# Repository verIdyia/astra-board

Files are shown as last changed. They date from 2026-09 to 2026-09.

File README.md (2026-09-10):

# Astra Board

ESP32-C3 development board built as a documented AI-assisted PCB experiment.

## Status

**Manufacturing paused due to cost (2026-09-10).** The owner reported approximately **US$123 for Standard PCBA** and **US$85 for Economic PCBA** in the 10-board quote discussion, and chose to stop procurement. These are owner-reported figures, not an independently verified complete checkout total; shipping/tax inclusion and complete LED assembly are unconfirmed. No order or payment was submitted.

KiCad ERC and DRC passed with zero reported violations on 2026-09-10. The repository QR is added and independently decoded from the KiCad export. Manufacturing files are in `fab/rev2/`; supplier assembly-preview verification is pending. JLCPCB currently rejects the LED for Economic PCBA; alternative-part eligibility is inconsistent and remains unresolved. The support inquiry is drafted but unsent. Revision 2 includes the electrical-review routing and power-copper repair. USB signal integrity and regulator temperature remain unverified. No hardware has been manufactured or tested.

## Hardware

- 60 × 40 mm, two layers, front-side SMT
- ESP32-C3-WROOM-02, native USB-C, 3.3 V regulator
- Eight addressable RGB LEDs, two user buttons, BOOT and RESET
- Passive buzzer, OLED header, Qwiic connector and GPIO expansion
- 16 SMT BOM lines / 50 assembled components; buzzer and two headers are owner-soldered

Open `hw/astra-board.kicad_pro` with KiCad 10. Local footprint variants are in `lib/Astra.pretty`; the project footprint table resolves them relative to the project.

See `BRIEF.md` for requirements, `parts/DECISIONS.md` for design choices and known limitations, and `log/` for the experiment record. `parts/bom-candidates.csv` records selected parts and sourcing evidence. Firmware and a machine-readable pinout are planned but not yet implemented.

Raw recordings, account responses, intermediate router output and draft manufacturing files are deliberately excluded. This repository is not yet a fabrication release.

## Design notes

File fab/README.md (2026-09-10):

# Fabrication status
`rev1/` is the current package for supplier review. It includes the repository QR, Gerbers, drills, BOM/CPL and machine-check reports. No order has been placed.
DRC and ERC report zero violations. BOM has 16 SMT lines / 50 components, and CPL has 50 top-side rows matching the schematic. BZ1, J3 and J4 are owner-soldered.
All exports use the absolute origin; CPL Y follows KiCad's Y-up convention. Rotations are raw KiCad angles and still require JLCPCB assembly-preview verification. Hardware and thermal performance are unverified.
The STEP preview remains local and omits the absent USB-C 3D model. Draft and intermediate artifacts are excluded from version control.

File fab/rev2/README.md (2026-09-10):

# Revision 2 manufacturing package — PCB silk REV 1.1

**Procurement paused by the owner due to cost on 2026-09-10.** Preserved for future supplier review; no order/payment submitted. Economic LED eligibility remains unresolved and supplier assembly preview is incomplete. ERC and DRC: zero violations. BOM: 16 lines, 50 SMT components; CPL: 50 front-side placements. Seven extended lines are justified in parts/DECISIONS.md. BZ1/J3/J4 are owner-soldered and excluded.

Gerber ZIP and CPL use the common absolute KiCad coordinate origin; negative CPL Y is intentional. JLCPCB placement rotations/polarity must be reviewed before ordering. STEP visualization in hw/export omits J1 because its installed model is missing.

USB routing was shortened and power routing/thermal copper increased. Controlled differential impedance, USB signal integrity, regulator temperature at load and physical QR scanning remain unverified. See reviews/2026-09-10-pcb-review.md and log/03-layout.md.

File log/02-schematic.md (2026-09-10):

# 02 — Schematic — 2026-09-10 15:26–15:28 KST

## Phase
Schematic completed; moving to layout.

## What happened
Built three hierarchical pages with KiCad MCP batch placement, sourcing properties and global net labels. Native USB maps to GPIO18/19; I2C GPIO4/5; pixels GPIO6; buzzer GPIO7; user buttons GPIO0/1; BOOT GPIO9. GPIO2/8 receive external pull-ups. Expansion carries six remaining GPIOs, 3V3, 5V and two grounds. Last LED output and USB SBU pins are deliberately unconnected.

## Human interventions
No schematic intervention. Repo URL question remains pending for layout QR.

## Verification
- ERC errors: 0; warnings: 0 on the first run.
- DRC: not run yet.
- kicad-cli sch erc --format json generated hw/export/erc-attempt1.json.
- kicad-cli XML netlist export verified 53 physical components: 50 SMT, 3 owner-soldered THT. Every component has LCSC and JLC_BASIC; USB and I2C endpoint checks passed.
- Default KiCad ignored checks are recorded in the JSON; no check was disabled by the agent. In particular footprint-filter checking is a default ignored item, so library existence is checked separately.
- SVG exports of all three pages are in hw/export/schematic/.
- Unverified: rendered-page visual QA, analog stability/thermal behavior, hardware operation. ERC does not prove those.
- MCP created a PCB with 53 footprints and assigned 188 pads; NC/NPTH pads were intentionally unmatched.

## Scoreboard
ERC 0 / DRC not run / weekly usage 65%→66% / 5h absent / human time not measured.

## Media candidates
Raw: media/raw/run01-20260910-151816.mov.
- 00:05:20 — parts gate, before schematic work
- 00:09:22 — first ERC, zero violations

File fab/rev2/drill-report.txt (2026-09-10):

Drill report for astra-board.kicad_pcb
Created on 2026-09-10T19:54:18

Copper Layer Stackup:
    =============================================================
    L1 :  F.Cu                      front
    L2 :  B.Cu                      back

Drill file 'astra-board-PTH.drl' contains
    plated through holes:
    =============================================================
    T1  0.300mm  0.0118"  (57 holes))
    T2  0.300mm  0.0118"  (12 holes))
    T3  0.600mm  0.0236"  (4 holes)  (with 4 slots)
    T4  1.000mm  0.0394"  (16 holes))

    Total plated holes count 89

Drill file 'astra-board-NPTH.drl' contains
    unplated through holes:
    =============================================================
    T1  0.650mm  0.0256"  (2 holes))

    Total unplated holes count 2

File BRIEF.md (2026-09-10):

# astra-board — project brief

Read this before doing anything. `AGENTS.md` next to this file has the working rules.

## Why this project exists

The owner is a PCB / embedded firmware engineer (6 years, memory burn-in boards, I2C/SPI device firmware). This month there are many posts claiming GPT-6 Astra can one-shot a PCB. This project tests that claim end to end, honestly, and documents it publicly on X.

The rule of the experiment: **the human does not open the schematic or PCB editor.** The human writes prompts, reviews outputs, approves the JLCPCB payment, and solders the through-hole parts. Everything else is done by Astra through the KiCad MCP server, `kicad-cli`, and (only where unavoidable) Computer Use.

Wins and failures are both published. Do not hide errors, do not paper over an ERC/DRC violation, do not claim something is verified when it is not.

## What we are building

A small dev board that is easy for an AI agent to write firmware for. It will be given away to a few people on X; they should be able to plug it in, point Codex/Claude at this repo, and say "make it do something."

Board concept:

- MCU: ESP32-C3 module (native USB serial/JTAG, WiFi, Arduino / ESP-IDF / MicroPython support, very well represented in training data). If you believe a different part is clearly better for this purpose, say so in `parts/DECISIONS.md` with reasons, but the default is C3.
- Power: USB-C receptacle (16-pin, 5.1 kΩ CC pull-downs), 5 V → 3.3 V LDO rated ≥ 600 mA (WiFi TX peaks), proper decoupling.
- Things that give immediate visible / audible feedback:
  - 8 × addressable RGB LEDs (WS2812B family or compatible), in a row or arc
  - 2 × user tactile buttons, plus BOOT and RESET buttons
  - 1 × passive buzzer with a transistor driver
  - 0.96" I2C OLED (SSD1306, 4-pin module) on a through-hole header — the human solders this
- Expansion: 1 × Qwiic / STEMMA QT connector (JST SH 1.0 mm, 4-pin) on the same I2C bus, and a through-hole header breaking out the remaining GPIOs, 3V3, 5V, GND.
- Silkscreen: board name, pin labels on every header, a QR code pointing at this repo.
- Repo will contain `board.json` (machine-readable pinout) and firmware examples. Example firmware #1: a "quota gauge" that reads a JSON endpoint and shows remaining Astra / Claude usage on the LEDs and OLED.

## Hard constraints

- 2-layer, single-side SMT, JLCPCB Economic PCBA. Board size target ≤ 60 × 40 mm.
- JLCPCB **basic** parts first. Every **extended** part costs a feeder fee; each one must be justified in `parts/DECISIONS.md`. Aim for ≤ 4 extended parts (module, USB-C, Qwiic, LEDs are the likely ones).
- Passives 0603 or larger (hand rework must be possible). No BGA, no QFN with exposed pad unless it is inside the module.
- Through-hole parts (headers, OLED header, buzzer if THT) are **not** assembled by JLCPCB; the human solders them. Keep them few.
- SMT part count ≤ 20 lines in the BOM.
- Design rules: ≥ 0.2 mm trace / 0.2 mm clearance, ≥ 0.2 mm drill, ≥ 0.6 mm via pad (JLCPCB standard capabilities).
- Only use symbols and footprints that actually exist in the KiCad 10 standard libraries or in `lib/` inside this project. Never invent a footprint. If a part needs a footprint that does not exist, say so and stop.
- Every LCSC part number must be verified against the JLCPCB parts database (the MCP server ships `download_jlcpcb.py`) or jlcpcb.com. Never guess an LCSC number. Mark anything you could not verify as UNVERIFIED.

## Phases and gates

Run the phases **back to back in one session** — this is the point of the experiment: can it go start to finish in one day? Each phase has a machine-checkable gate. Pass the gate, write the phase log, move on. Do not wait for the human between phases.

There are exactly **two hard stops** where you wait for the human:

- **Before payment on JLCPCB.** Show the cart total, the assembly preview (part rotations, polarity), and the extended-part count. The human clicks pay. Never submit payment yourself.
- **A gate that fails after two honest attempts.** Stop, write down what is failing and what you tried, and ask. Do not loop.

1. **Parts** → `parts/bom-candidates.csv` (columns: `role, qty, mpn, manufacturer, lcsc, basic_or_extended, unit_price_usd_at_10, stock, kicad_symbol, kicad_footprint, datasheet_url, note`) + `parts/DECISIONS.md` (MCU module choice — compare at least ESP32-C3-MINI-1 vs ESP32-C3-WROOM-02 — LDO, LED package, USB-C receptacle, buzzer + driver, Qwiic connector, button footprint, every extended part and why it earns its feeder fee, estimated PCBA cost for 10 boards). Prefer stock > 1,000. Gate: every LCSC number verified; every symbol/footprint name confirmed to exist.
2. **Schematic** → `hw/astra-board.kicad_sch`. Gate: `kicad-cli sch erc --format json` reports 0 errors; warnings listed with a reason each.
3. **Layout** → `hw/astra-board.kicad_pcb`. Gate: `kicad-cli pcb drc --format json --exit-code-violations` exits 0. Export SVG (both sides) and STEP to `hw/export/` for the human to look at later.
4. **Fab files** → `fab/` (gerbers, drill, POS, BOM/CPL in JLCPCB column format). Gate: files present, BOM lines match the schematic, CPL row count matches SMT part count.
5. **Order** → JLCPCB via browser up to the payment page. **Hard stop.**
6. **Firmware** → `fw/` examples + `board.json` + `fw/AGENTS.md` for the people who receive the board. Gate: the example firmware builds for the chosen module. Hardware test happens when the boards arrive.

Write a log entry per phase (`log/01-parts.md`, `log/02-schematic.md`, … using `log/TEMPLATE.md`). The human will read them afterwards, not during.

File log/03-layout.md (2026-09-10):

# 03 — Layout — 2026-09-10 15:28–15:42 KST

## Phase
Layout gate failed twice. Stopped; no fabrication package or order created.

## What happened
Placed 53 footprints on a 60 × 40 mm, two-layer board with SMT on the front. Corrected mechanical placement conflicts with file-based geometry checks. Routed using local Freerouting 2.4.1, then checked the saved result with KiCad CLI. Added rear ground fill and a front 3V3 thermal copper region. Header labels are on the back; buttons, board name and LED indices are on the front. Public-repo QR remains pending the URL.

The standard module footprint had 0.2 mm thermal drills. A documented derivative in lib/Astra.pretty increases the twelve holes to 0.3 mm without changing pad locations/sizes. This fixed the drill constraint; no drill violations remain. No KiCad editor was used.

## Attempts and what failed
1. `kicad-cli pcb drc --format json --exit-code-violations --refill-zones -o hw/export/drc-attempt1.json hw/astra-board.kicad_pcb`: exit 5; 70 errors, 65 warnings, 0 unconnected. Errors: 66 undersized 0.15 mm trace segments, two courtyard overlaps and two copper-edge clearances. Warnings: 30 undersized text, 20 silk overlap, nine silk over copper, six silk-edge clipping.
2. Moved C2/R8/J2 to resolve mechanical/edge issues. Moved problematic body outlines and LED pin-number text to fabrication layer, enlarged actual silk text to 0.8 mm, and repositioned labels. Removed prior routing and rerouted with `--router.automatic_neckdown=false --router.neck_width_um=0`; exported DSN smd_smd clearance also raised from the exporter's 0.05 mm to 0.2 mm. CLI DRC with the same flags, output drc-attempt2.json: exit 5; 32 errors and 14 warnings in violations, plus two unconnected-item errors. Total 34 errors / 14 warnings. Thirty-one trace segments remain 0.15 mm despite the requested router override. One thermal connection at U2 pad 2 has only one required spoke; two disconnected items are islands within the 3V3 zone. All prior placement, edge and silk-size/overlap errors are gone.

The second SES still contained width values 1500 and 2000 in its coordinate scale. Those were printed before import; I should have investigated the remaining 1500 widths instead of assuming the flag had worked. The actual router behavior is not yet explained (fanout or settings precedence are possibilities, not verified causes).

The 14 library-footprint mismatch warnings are D1–D8, SW1–SW4, U1 and J1, whose silk graphics were relocated to F.Fab. They need matching local library variants or another consistent artwork solution. They have not been suppressed.

A requested Power net class was saved in the project, but the MCP warned its in-memory assignment failed; DSN still places all nets in kicad_default. Therefore the intended 0.4 mm power routing was NOT achieved. Do not claim otherwise.

SES import updated disk without refreshing the MCP file-change fingerprint. Subsequent autosaves were refused. Reloaded from disk and reapplied zones/labels; did not force-overwrite the routed file. No server code was modified.

## Human interventions
No layout-editor intervention. Asking for authorization to continue after the two-failure hard stop. Repo URL question remains unanswered.

## Verification
- ERC: final recheck after local footprint reference change, 0 errors / 0 warnings (erc-final.json).
- DRC final: 34 errors including two unconnected-item reports; 14 warnings; exit 5.
- Minimum drill change verified by DRC (no drill violations); minimum trace requirement still fails.
- Front and mirrored back SVGs and STEP successfully exported as review-NOT-FOR-FAB files.
- File-based rendered front silk/mask inspected; no screenshot used as design-rule verification.
- Unverified: QR, impedance/USB pair lengths, thermal/current performance, detailed datasheet mechanical match, successful final DRC, fab consistency, JLC assembly preview, firmware build and hardware.

## Scoreboard
ERC 0 / DRC 34 errors + 14 warnings / weekly usage 66%→68% (resumed session 65%→68%) / 5h absent / human time not measured.

## Media candidates
Raw: media/raw/run01-20260910-151816.mov.
- 00:09:22 — first schematic ERC passed
- 00:17:43 — first routed PCB DRC failed
- 00:21:44 — second DRC and hard stop

## Resumed session — 2026-09-10 15:45–15:54 KST
User authorized continued fixes and computer use. No editor was running. Recording run02 started with a persistent display-awake assertion; weekly usage 68%→70%.

New gate attempt 1 (overall attempt3): 31 track-width errors, two unconnected errors, zero warnings. The earlier claim that MCP widened the tracks was incorrect: the advertised modify_trace parameter traceUuid is rejected by the backend as “Missing trace identifier”; its nested success:false was initially missed. The tool did not change those widths. No server code was changed. The local library mismatches were fixed by generating four artwork variants directly from existing standard library parts, then synchronizing 14 schematic and board references. Two failed SWIG copy attempts were abandoned in favor of loading the known original library footprints. The minimum-hole rule was updated to 0.2 mm; actual existing 0.3 mm drills remain unchanged.

New gate attempt 2 (overall attempt4): seven unconnected errors and three dangling-track warnings, exit 5. Width and clearance errors are now zero; library mismatch warnings are zero. KiCad-bundled Python widened all 31 affected tracks and reread the saved board to verify the minimum width is 0.2 mm. A prospective shape-clearance check found one conflict with a 3V3 via; a 0.035 mm shift of the connected 45-degree/vertical GND segments removed that conflict. No cross-net GND pad/track/via collisions remained in the preflight check, and DRC confirmed no clearance failures.

The remaining seven connectivity errors and three dangling warnings are all on +3V3, around U2 and C4/C5/C6. The earlier large 3V3 pour had two disconnected sections even with solid connections/island removal. It was removed for replacement with a smaller solid thermal region, but the advertised MCP add_zone command returned “Unknown command”. I ran DRC before resolving that command failure, so the replacement zone is absent. The affected traces had previously depended on that pour for connectivity. Next correction must establish explicit 3V3 copper continuity and sufficient LDO thermal copper, verify that it is saved, then run the gate; do not merely suppress these reports.

All four local footprint variants are based on existing standard parts; no pad geometry changed beyond the already documented twelve module drill enlargements. Refreshed BOM footprint references accordingly. Thermal behavior, USB signal integrity, repo QR and manufacturing remain unverified. No fab/order/firmware phase was started.

Human interventions: user permitted this resumed correction round; another two-attempt stop reached. Further fixes await permission. Public repo URL is still missing.

Media candidates: media/raw/run02-20260910-154511.mov.
- 00:03:27 — resumed DRC exposes failed width command
- 00:07:17 — saved widths verified; remaining 3V3 connectivity failure

## Third repair session — 2026-09-10 15:57–16:02 KST
Human intervention: user said “응” to resume the failed layout repair.
Restored the 3V3 zone, directly connected pads, and added one clearance-checked 0.4 mm back-layer bridge with 0.6/0.3 mm vias. Filled copper was saved using a retained pcbnew ZONE_FILLER instance.
Verification: drc-attempt5: 2 unconnected errors, 0 other violations; drc-attempt6: 1 unconnected error, 0 other violations (warnings included). Layout gate still fails; not ready for fabrication. Two straight-bridge candidate searches for the remaining island collided with existing copper. Those failed candidates were not written. Stop retained per AGENTS/BRIEF; remaining connection needs a changed route.
Quota: weekly 70% at start and end; five-hour window unavailable.
Media candidates: run03 00:00:00 repair start; 00:04:12 remaining island and stop. Existing review exports predate this repair and are not fabrication artifacts.

## Fourth repair session — 2026-09-10 16:03 KST
Human intervention: user said “응” to authorize rerouting the last island.
Moved a short EN segment to B.Cu. The initial 1.0 mm via separation left the 3V3 passage closed (attempt7: one unconnected). Increased spacing to 1.4 mm; attempt8 exits 0, zero errors/warnings/unconnected. No rules relaxed. Saved zone fill retained.
ERC rerun: zero violations in erc-final.json. Front/back SVGs and STEP refreshed. Exported SVGs were rendered and inspected for copper continuity, antenna clearance and header label readability. STEP omits J1 because its installed 3D model is absent; mechanical assembly and hardware behavior remain unverified.
The DRC gate passes, but the required repository QR is still pending the actual public URL. Asked user for URL; no placeholder inserted.
Quota at start 70%, DRC pass 71%; five-hour window unavailable.
Media candidates: run04-20260910-160313.mov, 00:00:48 EN crossing change; 00:01:23 DRC passes. Latest exports remain named NOT-FOR-FAB while QR is pending.

## Repository QR completion — 2026-09-10 16:15 KST
Public repository created after user authentication. Added its QR on B.Silkscreen, 11.1 mm square with 0.3 mm cells and quiet border. DRC after the QR: zero violations and zero unconnected. Independent ZXing decode of the actual KiCad SVG raster matched https://github.com/verIdyia/astra-board. Physical scan quality awaits fabricated hardware. Front/back SVG and STEP refreshed; STEP still omits the absent J1 model.
Media: run05 00:01:02 QR insertion; 00:02:10 fabrication validation.

## Electrical review repair — 2026-09-10 19:11–19:30 KST — paused
Human intervention: user authorized fixing the review findings and proceeding directly. No PCB editor was open at the pre-edit check. Work stayed in hw/rework; published PCB and fabrication files were not overwritten.
Moved USB-C, module and USB resistors; shortened the MCU-side P/N traces to approximately 2.325/2.408 mm with no vias. Assigned power nets to the 0.6 mm class, corrected router-generated undersized tracks to at least 0.2 mm, moved the existing module bulk capacitor closer, and increased regulator-tab front copper to approximately 497 mm². This is candidate geometry, not electrical qualification.
First complete gate: kicad-cli pcb drc --format json --exit-code-violations, report hw/rework/drc1.json, failed: one courtyard overlap, seven dangling-via warnings, three unconnected reports. A saved follow-up candidate (rev2-fixed.kicad_pcb) addresses those items; it was not subjected to a second full DRC because USB routing remained unsatisfactory. Native courtyard checks reported zero overlaps for that candidate.
Two local USB-ESD route attempts then failed. First, rotated U4's power/ground connections obstructed signal escape; second, removing the two obstructing segments allowed both ESD pin ties, but the N connection to the connector still could not be routed by the local clearance-aware search. No complete rotated-USB board was saved. Stopped per AGENTS.md: do not loop on the same failing fix more than twice. Proposed next step is a new ESD placement and pair-first routing with surrounding copper rerouted afterwards.
Verification: revised DRC is NOT passed; schematic unchanged and ERC not rerun in this repair (previous published ERC zero). Thermal behavior, USB impedance/length matching, assembled-board operation and JLC placement preview remain unverified. No revised fab exports, uploads, order or payment occurred. Existing fab/rev1 is superseded in intent by the pending electrical repair and should not be ordered.
Quota: weekly 74% to 77%; five-hour window unavailable. Recording stopped normally.
Media candidates: media/raw/run07-20260910-191138.mov.
- 00:08:19 — first complete revised-layout DRC
- 00:18:40 — two local USB route failures and preserved-candidate stop

## Resumed USB repair — 2026-09-10 19:31 KST — two-gate stop
User authorized continuation. Recording run08 started; the PCB editor was not running. Reversed the local search direction to escape from the connector's narrow USB pads at their exact coordinates. This avoided the coarse 0.2 mm search-grid alignment issue and produced a complete saved USB candidate. Routing all narrow-pad connections this way succeeded; previous unsuccessful searches were not evidence that the physical routing was impossible.
First resumed gate, hw/rework/drc-usb1.json: four errors (two NPTH-to-copper clearances, one BUZZ_BASE-to-Q1 clearance, one starved J1 ground thermal), plus one unconnected item; zero warnings. Reduced two short 5V neckdown segments from 0.45 to 0.35 mm to clear the connector locating hole, rerouted the BUZZ_BASE segment, made the connector ground pads solid-connected to the ground pour, and connected the isolated ground region.
Second resumed gate, hw/rework/drc-usb2.json: ZERO errors, ZERO unconnected items, ONE warning, exit 5. Two same-net ground vias at (149.5,109.9375) and (149.5,110.1375) have overlapping 0.3 mm drills. The local search ignored same-net copper obstacles and consequently did not enforce physical drill separation between these vias. No warning was excluded. Stop per BRIEF after two failed gates. Next fix: reuse the existing ground via instead of the new adjacent via, preserving the copper connection, then refill and rerun DRC.
Last candidate: hw/rework/gate2.kicad_pcb. Original PCB and fab/rev1 remain untouched. ERC not rerun because the schematic did not change. USB signal integrity/impedance and thermal operation are unverified; DRC alone cannot verify them. No fabrication update, browser upload, order or payment.
Media candidates: run08-20260910-193144.mov, connector-escape repaired/first DRC and final single-warning stop; exact timestamps are in the adjacent markers TSV. Usage at session start: weekly 77%; five-hour absent. End usage recorded in log/usage.tsv.

## Via repair and layout gate passed — 2026-09-10 19:52–19:54 KST
User authorized continuing. Removed the redundant GND via; its attached copper endpoints are inside the retained 0.6 mm via annulus, so no separate drill is required. Refilling saved copper and running kicad-cli pcb drc --format json --exit-code-violations produced zero violations and zero unconnected items, exit 0. No rule or severity changed.
Promoted the verified candidate to hw/astra-board.kicad_pcb and its power net assignments to the main project; updated silk REV 1.0 to REV 1.1. Reran DRC on the main board with its actual library table: zero violations/unconnected, exit 0. Schematic ERC rerun: zero violations. Reports are in fab/rev2.
Front/back SVGs were exported and inspected. The actual back SVG raster still decodes the exact repository URL with ZXing. STEP exported, but the installed USB-C model remains missing. Electrical/thermal hardware qualification and supplier assembly preview remain unverified. Quota: weekly 77% at start and layout pass, five-hour absent.
Media: run09-20260910-195254.mov, 00:00:22 duplicate-via correction/DRC; later revised Gerber upload.

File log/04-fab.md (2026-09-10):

# 04 — fabrication draft — 2026-09-10 16:05 KST
## Phase
Fab preparation; final release pending required repository QR URL.
## What happened
Generated eight Gerber layers, separate PTH/NPTH drills and report, raw positions, JLCPCB BOM and CPL in fab/draft. No fabrication ZIP released or uploaded.
## Human interventions
Asked for the public repository URL required for the silkscreen QR. Awaiting response.
## Verification
ERC: 0 violations. DRC attempt8: 0 violations, 0 unconnected, exit 0.
BOM: 16 SMT lines, 50 components. CPL: 50 top-side rows. Reference sets exactly match schematic SMT assembly fields. Owner-soldered BZ1/J3/J4 excluded.
Unverified: JLCPCB assembly orientation/polarity preview, final QR, supplier live allocation, thermal and hardware behavior. STEP lacks USB-C 3D model.
## Scoreboard
DRC 0 / ERC 0 / five-hour unavailable / weekly 70%→71% at DRC pass.
## Media candidates
run04-20260910-160313.mov: 00:01:23 DRC pass; updated front/back SVGs.

## Manufacturing export gate passed — 2026-09-10 16:16 KST
QR requirement resolved. Current exports are in fab/rev1 with Gerber ZIP, separate drills, BOM, CPL and validation report. All files are non-empty; SMT BOM 16 lines / 50 components and CPL 50 top-side rows exactly match schematic SMT references. Current DRC and ERC reports accompany the package. Board SHA-256 recorded in validation.json.
Supplier assembly preview, rotations, polarity and final stock allocation remain unverified. Uploaded only the Gerber ZIP to JLCPCB for review. No order/payment submitted.
Usage: weekly 71% at QR start →72% at fabrication gate; five-hour unavailable.
Media: run05-20260910-161424.mov, 00:01:02 QR, 00:02:10 fabrication gate.

## Revised manufacturing gate — 2026-09-10 19:54 KST
Generated fab/rev2 from the promoted board: nine Gerber layers including empty B.Paste, separate PTH/NPTH drills, ZIP, raw positions, BOM/CPL, front/back SVG and ERC/DRC reports. Regenerated BOM directly from fresh schematic XML assembly fields, rather than copying the previous file. BOM reference set and CPL reference set exactly match: 16 SMT lines, 50 components, 50 top-side CPL rows, seven extended lines. All Gerber/drill files are non-empty; board SHA recorded in validation.json. Exported QR independently decoded to the correct public repository. No assembly rotations, supplier allocation or hardware behavior verified yet. Old rev1 marked superseded.
Media: run09, DRC pass and revised Gerber upload. No additional human intervention beyond permission to resume repair.

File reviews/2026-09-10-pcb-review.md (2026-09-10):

# PCB review — 2026-09-10

Scope: read-only review of the current board and selected power/USB connections. No PCB or schematic edits. This is not a full manufacturer footprint audit or hardware qualification.

## Findings

1. **High priority — USB routing needs revision before release.** R14-to-U1 USB_P tracks total 60.91 mm; R15-to-U1 USB_N total 42.04 mm, a difference of 18.87 mm. Each MCU-side net has two vias and uses both copper layers; the connector-side USB_CONN_N has another three vias whereas USB_CONN_P has none. R14/R15 are around x=115 mm while U1 USB pins are x=153.75 mm. These are separate routes, not a consistently parallel differential pair, and the series resistors are far from the MCU. Recommend placing R14/R15 by the MCU and rerouting USB together over continuous ground with controlled differential geometry. Full-speed USB might work, but successful enumeration and compliance cannot be inferred from DRC.

2. **Medium priority — power distribution and local bulk capacitance need improvement.** All explicit +5V tracks are 0.2 mm wide (147.39 mm summed over the entire branched net, NOT one current path). Almost all explicit +3V3 tracks are also 0.2 mm; the regulator has a copper zone but the feed to the module remains narrow. The eight LEDs share 5V with the regulator. C1 is only 100 nF near the module; all three 10 uF output capacitors are near the regulator, with the closest bulk-cap positive pad about 9.36 mm from U1's 3V3 pad. Widen the common supply paths or use suitable pours and add/relocate bulk capacitance at the module supply entry. Exact voltage drop and temperature rise require branch-current and copper-stack assumptions; no failure threshold is claimed from trace width alone.

3. **Medium priority — LDO thermal capacity is not verified.** At the BRIEF's 600 mA load, a 5V-to-3.3V linear regulator dissipates approximately (5-3.3)*0.6 = 1.02 W, excluding quiescent loss. The 1 A nameplate rating does not establish continuous 600 mA operation on this copper area. Verify the selected part's thermal data against the actual copper and ambient conditions, or reduce dissipation. This is a thermal-margin concern, not an observed shutdown.

## Verification

- Standard kicad-cli pcb drc --format json --exit-code-violations: exit 0, zero violations and zero unconnected items, hw/export/drc-review.json. The initial --refill-zones invocation did not produce a report in this environment; therefore no new successful refill is claimed. Current saved board hash exactly matches the already-validated fab/rev1/validation.json board hash.
- kicad-cli sch erc: zero violations, /tmp/astra-review-erc.json.
- Inspected U1, U2, U4, USB-C, USB series resistors and power capacitor pad nets and positions using read-only pcbnew.
- Board and manufacturing revision match. No order was placed. Supplier assembly rotations remain unverified.
- Physical USB performance, RF range, Wi-Fi load transients, thermal performance and assembled QR readability remain unverified.

## Sources

Espressif USB layout guidance calls for parallel equal-length 90 ohm differential routing, few transitions with return vias, continuous reference ground and components near the chip:
https://docs.espressif.com/projects/esp-hardware-design-guidelines/en/latest/esp32c3/pcb-layout-design.html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

Power-supply guidance:
https://docs.espressif.com/projects/esp-hardware-design-guidelines/en/latest/esp32c3/schematic-checklist.html

## Session limitations

Recording startup printed success but ffmpeg immediately failed with Invalid device index; no working recording was available. Usage lookup failed because the endpoint hostname could not resolve. No alternative account lookup was attempted. Source files were not changed, and the review was not pushed to GitHub.

## Repair update — 2026-09-10 19:57 KST
The review above describes the old rev1 board. Revised main PCB and fab/rev2 now pass CLI DRC with zero errors, warnings and unconnected items; ERC also has zero violations. USB connector moved to the right edge, module shifted left and series resistors relocated next to MCU pins. MCU-side USB_P/USB_N routing is approximately 2.325/2.408 mm with no vias, versus 60.91/42.04 mm in the reviewed board. Connector-side USB routing was also shortened, but N still has layer transitions whereas P does not. This is a mitigation, not verified matched differential routing or impedance.
Power nets now have explicit 0.6 mm class assignments and wider routing; local neckdowns remain, including two 0.35 mm segments near the USB locating hole. Existing C5 bulk capacitor moved close to the module's supply pin. Front regulator-tab copper was enlarged to approximately 497 mm²; full-load thermal behavior is not established by this area and remains a hardware test requirement. No circuit/BOM additions. Supplier placement and polarity preview still pending.

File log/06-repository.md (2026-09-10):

# Repository preparation — 2026-09-10
User requested creating the repository before choosing the QR URL. Initialized local astra-board Git repository on main. Excluded raw screen recordings, raw account-usage responses, local KiCad preferences, locks and environment files from version control.
GitHub CLI is installed but no GitHub host is authenticated. Started the official gh device login flow; user authentication is required before remote creation. No remote repository created and no files pushed yet. Intended repository is public astra-board, consistent with the public experiment brief. No credentials or device code recorded here.
Usage at preparation: weekly 71%; five-hour window unavailable. No KiCad or browser interaction during this preparation.

Authentication completed as verIdyia. Selected design sources, local footprints, sourcing evidence, curated logs and reproducibility scripts for the initial commit. Raw account responses, recordings, quota TSV, draft manufacturing files and intermediate exports are excluded. Staged source scan found no common token/private-key patterns. Commit email is the GitHub account's noreply address. Repository creation requested by the user; public visibility follows BRIEF.

Created and pushed public verIdyia/astra-board, default branch main. Added the verified repository QR and selected final manufacturing exports in a follow-up commit. The fabrication package is for supplier review, not a claim of verified hardware.

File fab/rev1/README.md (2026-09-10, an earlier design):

# Superseded — do not order

This package predates the electrical-review repair. Use ../rev2 for supplier review. Neither package has verified assembly rotations or hardware operation.

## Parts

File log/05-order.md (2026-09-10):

# 05 — order access smoke test — 2026-09-10
Opened the actual JLCPCB site and quote page in the Codex in-app browser. Gerber upload control is available. No files uploaded, no cart created, no order placed or payment submitted. Final fabrication files await the repository URL for the mandatory QR. Account login, assembly preview, stock allocation, shipping and payable total remain unverified.

## Supplier quote preparation — 2026-09-10 16:17 KST
Uploaded fab/rev1/astra-board-gerbers.zip. JLCPCB detected 2 layers, 40×60 mm. Set quantity 10, Economic PCBA, top side, 1.6 mm FR-4, green mask, white silk, tented vias and LeadFree HASL. PCBA quantity displays 10. Bare-PCB price displays $5; this is NOT an assembly total or payable cart total.
NEXT is preceded by a prechecked assembly-service Terms and Conditions checkbox. Did not click NEXT. Requested explicit user confirmation of those terms under the computer-use tool's action-time confirmation rule. The site displays Sign In; account authentication may also be needed. BOM/CPL not yet uploaded; no assembly preview, final total, order or payment.

## Google login check — 2026-09-10 16:26 KST
User authorized using Google sign-in if available. Selected JLCPCB Sign In, then Sign in with Google. The current in-app browser has no active Google session: Google displays an empty email/phone login form. Left the login tab visible for the user; no credentials entered. Assembly terms confirmation remains pending. No order/payment submitted. Quote before login displayed $6.20 for bare PCB plus lead-free finish, excluding assembly and shipping.
Recording run06 covers the login navigation only; stopped before user credential entry. Weekly usage 72% at start.

## Chrome revised quote — 2026-09-10 19:57 KST
Chrome quote page shows My Account; login is complete. Previous upload attempt lost its file-chooser event and the automation session reset without uploading. Opened a dedicated Chrome quote tab and used its actual upload control; revised fab/rev2/astra-board-rev2-gerbers.zip uploaded successfully. JLCPCB reports a 2-layer 40x60 mm board. Selected quantity 10, Economic, Top Side, LeadFree HASL; other base options remain standard 1.6 mm FR4, green, white, tented. No BOM/CPL uploaded yet.
The Next button is preceded by an automatically checked agreement to the Terms and Conditions of JLCPCB Assembly Service. Paused before Next under the computer-use tool's action-time agreement confirmation requirement. User's generic continuation messages authorized design repair but did not explicitly accept those terms. Request explicit permission for this agreement, then proceed to BOM/CPL matching and assembly preview. No total assembly price, cart, order or payment is claimed. The live Chrome tab is marked for handoff.
Media: run09, duplicate-via DRC pass and revised Gerber quote. Layout quota 77%; fab gate 78%; five-hour absent.

## Assembly matching — 2026-09-10 20:02–20:09 KST — supplier blocker
User explicitly approved the assembly-service terms. Clicked Next, entered the PCB assembly workflow, uploaded fab/rev2/BOM.csv and CPL.csv, and processed them. The site confirmed 16 matched lines, but automatically excluded the eight C2874885 LEDs per board as Standard Only. All other 15 rows are selected. Did not advance an incomplete assembly.
Two alternatives were investigated and attempted: C55109525 V7 and C52941391 V6. Economic filters and part-detail pages indicate support, but both actual selection attempts show a Standard-only rejection. The quote itself remains Economic, Top Side, qty 10. The V6 PDF pin/land geometry was inspected using the PDF skill with bundled pypdfium2 fallback (Poppler executable absent). A TME PDF fetch was blocked; the exact LCSC-hosted manufacturer PDF succeeded. V7 datasheet was not found and no V7 compatibility claim is made.
No schematic/PCB/BOM substitution was applied. Previous ERC/DRC remain zero; no new circuit checks needed for read-only investigation. BOM/CPL are uploaded, but assembly rotations/polarity, complete supplier allocation and payable total remain unverified. Stop after two failed supplier-selection attempts; draft a support inquiry and request user authorization before sending. Chrome quote tab marked for handoff. No order/payment or outbound support message.
Quota: weekly 78% at session start; end usage in log/usage.tsv. Raw recording run10-20260910-200200.mov. Media: 00:06:51 supplier LED restriction; end marker records stop.

## Owner-directed budget pause — 2026-09-10 20:30 KST

### What happened
The owner reported roughly US$123 for Standard and US$85 for Economic in the 10-board quote discussion, then requested updating the repository and pausing because the cost was too high. These totals are user-reported, not verified checkout figures; shipping/tax inclusion and complete LED population remain unknown. No browser interaction or design modification was performed in this documentation session. README, manufacturing-package status and DECISIONS now record the pause. Support inquiry remains unsent. No order or payment was submitted.
A read-only browser inspection between the previous recorded session and this update showed Standard selected; its cause was not established. This supersedes the earlier Economic screen state, not the BRIEF requirement. That short inspection was not recorded; this is a recording-process omission.

### Human interventions
The owner supplied the two quote amounts and explicitly stopped procurement for budget reasons. This overrides automatic phase progression; firmware and board.json remain unimplemented. No hard design constraint was relaxed.

### Verification
Existing fab/rev2 reports: ERC 0 errors / 0 warnings; DRC 0 violations / 0 unconnected. Hardware and fabrication payloads are unchanged; no fresh ERC/DRC run was needed for documentation edits. Checked the preserved board hash against validation.json and reviewed the Git diff. Unverified: supplier LED eligibility, complete assembly allocation, rotations/polarity, final price, USB signal integrity, regulator temperature and all physical hardware behavior.

### Scoreboard
Session start weekly usage 82%; five-hour window unavailable. Session end weekly usage 83% (82% → 83%), reset 09-15 11:37 KST, from log/usage.tsv. Human time was not measured.

### Media candidates
None for this documentation-only session; no KiCad, browser or hardware interaction. Previous run10 marker at 00:06:51 captures the supplier LED restriction.

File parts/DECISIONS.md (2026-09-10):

# Astra board decisions — 2026-09-10

## Constraints and verification
Plan: 60 × 40 mm, two copper layers, front-side SMT only, Economic PCBA. Minimum track/clearance 0.2 mm, drill 0.2 mm (user revision), via diameter 0.6 mm. No invented library items or fine-pitch exposed-pad ICs outside the module. Parts gate evidence is in `evidence/`: 19 verified JLCPCB snapshot entries and existing KiCad 10 library pairs, 16 SMT BOM lines / 50 SMT placements. Live checkout stock and the physical board remain unverified.

## MCU comparison
Choose ESP32-C3-WROOM-02-N4 (C2934560), 4 MB flash, native USB, onboard antenna. The installed standard library contains both its symbol and footprint. JLCPCB snapshot stock 3,702; quantity-10 unit price $2.8942. The catalog erroneously calls the module VFQFN-32-EP; do not use its automatically suggested QFN footprint. The Espressif module datasheet and exact RF_Module footprint determine the package.

ESP32-C3-MINI-1-N4 (C2838502) is smaller (13.2 × 16.6 mm versus WROOM 18 × 20 mm) and snapshot stock is 25,989, but the exact MINI-1 symbol and footprint are absent from installed KiCad 10 standard libraries and this repository. WROOM avoids a custom-library dependency. This keeps the BRIEF's default MCU family. Place the antenna at the board edge and preserve the library antenna keepout on both sides.

Source: https://documentation.espressif.com/esp32-c3-wroom-02_datasheet_en.html

## Power and passives
AMS1117-3.3 C6186 is the available Basic 3.3 V regulator meeting the ≥600 mA rating (1 A nominal). SOT-223 permits a larger thermal copper area than SOT-23 LDOs. At the module's 345 mA TX rating, dissipation is approximately (5−3.3)×0.345 = 0.59 W; rated output current does not establish thermal capability. Provide copper on the output tab and verify temperature on hardware. LED power stays on 5 V.

Use three Basic C7171 10 µF/16 V tantalums in parallel on the output (30 µF nominal, 27 µF at −10%) because AMS1117's compensation calls for tantalum bulk capacitance and the available Basic choice is 10 µF. Avoid assuming arbitrary MLCC-only stability. This trades two placements for avoiding another extended BOM line. Add local 100 nF decoupling. USB input uses 1 µF plus local LED/logic bypassing, rather than a large directly connected VBUS bulk capacitor. RC reset uses 5.1 kΩ and 1 µF.

Consolidate pull-ups and pull-downs to Basic 5.1 kΩ (including independent CC1/CC2 resistors). I2C starts at 100 kHz; receiver hardware will determine allowed bus capacitance. Other resistor values are 1 kΩ for buzzer drive/discharge, 330 Ω LED data, and 22 Ω USB data. All chip R/C parts are 0603 or larger.

## Feedback, connectors and assembly
LEDs: WS2812B-V5/W C2874885, 5050, matching the standard WS2812B pin layout. Eight LEDs in a row; individual bypass capacitors. TI SN74AHCT1G125DBVR C7484 translates 3.3 V data to 5 V with a specified TTL input threshold. Do not rely on a marginal 3.3 V high level into a 5 V pixel. Firmware must start dark and cap brightness; the board does not negotiate USB PD or guarantee full-white LEDs plus WiFi from every host port.

USB-C: HRO TYPE-C-31-M-12 C165948, exact standard footprint, 16 contacts. Its adjacent data-pad clearance is 0.2 mm. Shell anchors are part of the SMT connector's mechanical footprint; confirm their treatment in the PCBA preview. Add ST USBLC6-2SC6 C7519 ESD protection for a board repeatedly plugged into computers.

Qwiic: genuine JST SM04B-SRSS-TB(LF)(SN), C160404, standard horizontal footprint. Pins 1 GND, 2 3V3, 3 SDA, 4 SCL. Buttons: four TS-1088R-02026 C455280 with standard SW_SPST_TS-1088-xR020 footprint; keep one MPN for all four.

Buzzer: passive piezo TDK PS1240P02BT C76871, through-hole; owner solders it. Basic S8050 C2146 low-side driver uses pin 1 base, 2 emitter, 3 collector. A 1 kΩ resistor across the piezo provides discharge during the off half-cycle. This is piezoelectric, not an inductive magnetic buzzer. No active buzzer substitution.

Headers: C124378 1×4 for the off-board SSD1306 OLED, C124372 1×10 expansion, both through-hole and owner-soldered. OLED pin order is GND/3V3/SCL/SDA and must be matched to the supplied module before plugging in. The OLED module itself is a separate owner-supplied assembly, not a JLCPCB placement.

## Every extended SMT line and departure from the target
Seven extended SMT types exceed the BRIEF's **aim** of four, while keeping its hard assembly and 20-line limits:

| Part | Why the feeder fee is justified |
| --- | --- |
| ESP32-C3-WROOM-02-N4 | Required programmable wireless module with native USB |
| HRO USB-C | Required 16-contact USB-C interface |
| JST Qwiic | Required compatible expansion connector |
| WS2812B-V5/W | Required eight addressable RGB pixels |
| TS-1088R switch | Required four tactile buttons with a verified standard footprint; no Basic switch found |
| TI AHCT buffer | Guaranteed LED logic levels across supply and temperature |
| ST USBLC6 | USB ESD protection for the intended giveaway/use case |

THT buzzer and headers are also catalog Extended but incur no PCBA feeder charge because they are excluded from assembly. Every physical schematic part will retain its actual `LCSC` and `JLC_BASIC` field, including THT items.

## Estimate for 10 boards
Using quantity-10 pricing for every selected SMT line gives $5.7528 per board, $57.528 for ten, before attrition (conservative for lines bought in larger quantities). Published Economic setup $8.18, stencil $1.53, extended loading 7×$3.07=$21.49, plus roughly $2–4 placement fees yields approximately $91–93 before bare PCBs, possible anchor/manual processing or module inspection charges, shipping and tax. Budget approximately $110–140 total before shipping/tax and owner-supplied OLEDs; this is an estimate, not a checkout quote. The order page is authoritative.

Pricing source (checked 2026-09-10): https://jlcpcb.com/help/article/pcb-assembly-price

## Process adjustments
User confirmed the 5-hour usage window no longer exists. Keep it unavailable in legacy usage rows and report weekly usage; never substitute the Spark bucket. Screen recording requires an active display (device 2 on this machine), maintained with `caffeinate -u -d`; the original index 1 was a camera. These are workflow corrections, not board-constraint changes.

Public repository URL is pending user input for the required QR code; do not invent or encode a placeholder URL.

## Layout discovery: module thermal drills
The existing KiCad 10 RF_Module:ESP32-C3-WROOM-02 footprint includes twelve 0.2 mm thermal holes, incompatible with the BRIEF's ≥0.3 mm drill rule. Copied that existing footprint into lib/Astra.pretty/ESP32-C3-WROOM-02.kicad_mod and changed only those hole diameters to 0.3 mm; pad sizes (0.6 mm), positions, paste apertures, outline and antenna keepout are preserved. The local library reference is Astra:ESP32-C3-WROOM-02. This is an adaptation of the actual installed footprint, not a guessed land pattern. The MCP pad editor cannot select only the through-hole pads sharing pad number 19 (it would also add a drill to its SMT pad), so KiCad-bundled pcbnew performed this selective modification. The first save helper could not infer the empty library plugin; explicit KiCad S-expression plugin saved it successfully. Confirm drill and annular spacing in DRC; module center-pad wicking/assembly inspection remains part of the JLC preview.

Component references moved from crowded front silkscreen to the fabrication drawing. User-facing labels (headers, buttons, LED indices, board name) will remain on silkscreen. No circuit features were removed.

Local Freerouting 2.4.1 and Temurin JRE 25 were downloaded to /tmp/astra-routing because no working Java runtime/router was installed. KiCad MCP exports/imports DSN/SES; routing runs locally without uploading the design to a third-party routing service.

## Layout gate outcome
Two DRC attempts failed; see log/03-layout.md and hw/export/drc-attempt*.json. The second result has 31 undersized tracks, one thermal-spoke error, two isolated-zone connectivity errors and 14 library-mismatch warnings from relocated silk. Do not fabricate this revision. The new Power class did not propagate into DSN; actual routing remains default-class width, with some unwanted 0.15 mm segments. Further correction requires the user to release the BRIEF's two-failed-gates stop.

## User revision: minimum drill 0.2 mm
The user changed the permitted minimum drill to 0.2 mm after the layout stop. The on-disk BRIEF still read 0.3 mm when reread, so its drill line was synchronized to the user's explicit instruction. Trace width/clearance remain 0.2 mm and via pad diameter remains 0.6 mm. The earlier thermal-hole adaptation was made under the old constraint and is retained above as history; it is no longer necessary to satisfy the revised minimum. No PCB, library geometry or KiCad project setting was changed in this documentation-only update. The existing 0.3 mm holes remain compliant. Latest DRC failures were not drill violations, so this revision alone does not resolve the failed layout gate.

## Resumed layout corrections and current state
User authorized additional work and computer use. The board now references four local standard-library artwork variants (module, USB-C, switches, LEDs) whose silk-to-Fab changes match the placed instances; all 14 mismatch warnings are resolved. Other footprints remain standard. Minimum drill rule is 0.2 mm per revised BRIEF; existing 0.3 mm module holes remain compliant.

KiCad-bundled Python was needed because MCP modify_trace rejected its advertised traceUuid parameter and add_zone was unsupported. Actual saved trace widths now meet 0.2 mm, with one small GND path shift to preserve clearance. The previous 3V3 pour was removed during repair, and its replacement failed to create; current board therefore has seven +3V3 unconnected errors and three dangling-track warnings (drc-attempt4.json). This supersedes the earlier counts. It is NOT ready for fabrication. The two-attempt stop applies again. No DRC errors or warnings were disabled.

## Third authorized repair session
Restored the front 3V3 copper region with solid pad connections and island removal; this reduced seven unconnected reports to two. Added a 0.4 mm back-layer bridge at x=117.5 from y=109.2 to 110.85, with two 0.6 mm vias / 0.3 mm drills, joining the C6 island to the regulator region. Exact track/pad copper-shape checks preceded the edit. KiCad-bundled Python was used for zone configuration, filling and clearance-aware bridge construction, which the available working MCP interfaces do not expose. Keeping the ZONE_FILLER object alive allowed filling and saving without the previous crash.
A second straight back-layer bridge near x=128–129.6 collided with existing copper in both candidate searches and was not saved. Final DRC attempt6 still has one 3V3 island connection error, zero other violations. No checks were relaxed. Next repair should reroute the crossing signal or use a non-straight bridge after user release of the stop.

## Fourth authorized repair session — DRC passed
The user authorized rerouting the remaining island. The front EN trace separated the 3V3 region, while the back BOOT trace blocked a straight 3V3 bridge. Moved the EN segment from x=128.4 to x=129.8, y=107.1584, onto B.Cu using two 0.6 mm vias with 0.3 mm drills; trace width remains 0.2 mm. The initial 1.0 mm via spacing still closed the copper passage; increasing it to 1.4 mm allowed the filled 3V3 region to join. Saved copper was refilled and DRC attempt8 exits 0 with zero violations and zero unconnected items. No rules or severities were relaxed.
The existing Python fallback was used for the precise segment replacement and shape-clearance checks because the working MCP tools do not provide this atomic operation. ERC was rerun and remains zero violations.
Fab files are staged in fab/draft because the repository URL required by the QR requirement has not been supplied. No placeholder QR or invented URL was used. The STEP export exists but the installed library lacks the J1 USB-C 3D model; this limits mechanical visualization, not the footprint or copper checks. Browser access to the JLCPCB quote page succeeds; no design files uploaded and no order placed.

## Public repository and QR
Created the public repository https://github.com/verIdyia/astra-board after user-requested GitHub device authentication. Version control contains selected source files, local libraries, sourcing evidence and curated logs; raw recordings, raw account responses, intermediate router output and draft manufacturing artifacts are excluded.
Added a 37-cell QR including four-cell quiet border at 0.3 mm pitch (11.1 mm square) on back silkscreen. White background spans leave dark soldermask modules; coordinates are mirrored for back-side reading. It points to the real repository, with no URL shortener. Python pcbnew was required because no QR insertion tool is available. The exported KiCad SVG was rasterized and decoded independently with ZXing; exact repository URL matched. DRC with QR: zero violations and unconnected items. Physical printed-code readability awaits hardware.
Generated fab/rev1 with common absolute origin for Gerber, drills and CPL; raw KiCad rotations await supplier preview. Selected default economical green soldermask, white silk, two layers, 1.6 mm FR-4 and tented vias for the quote; no payment authorized to the agent.

## Electrical review repair — 2026-09-10, unverified candidate
User authorized correcting the PCB review and proceeding. Preserve the published board and fab/rev1 while working in ignored hw/rework/: do not replace manufacturing artifacts until the revised layout passes DRC. Existing rev1 passes geometric checks but has the electrical concerns in reviews/2026-09-10-pcb-review.md; it should not be ordered pending this repair.
Moved the USB-C connector to the right edge and the module leftward so the series resistors can sit immediately next to the MCU USB pins. Moved the BOOT switch and nearby passives/header to clear the module antenna and component courtyards. These are placement choices within the BRIEF, not changes to its features, board dimensions, BOM or hard constraints. No new BOM line or feeder fee was added.
Assigned +5V and +3V3 explicitly to a 0.6 mm Power net class; the previous class existed without net assignments. Local 0.45 mm power neckdowns and 0.2 mm signal tracks remain above the minimum. Moved the existing C5 bulk capacitor close to the module supply and enlarged the front 3V3 regulator-tab copper area; the measured candidate filled area is approximately 497 mm². This does not establish regulator thermal qualification: 600 mA at 5 V input dissipates about 1.02 W, and hardware temperature/load testing remains necessary.
MCP exported/imported DSN/SES; local Freerouting generated the changed placement's routes. KiCad-bundled pcbnew then widened undersized segments, configured/fill-saved copper zones and attempted clearance-aware local connections because the relevant advertised MCP modification interfaces are missing or broken. No server code, rule minimum, severity or violation exclusion was changed.
The first complete revised-layout DRC failed (one courtyard overlap, seven dangling-via warnings, three unconnected reports). A later candidate addressed those items but has not passed a complete gate. Two subsequent local USB-ESD routing attempts failed to connect USB_CONN_N after rotating U4; the second removed the two power/ground segments obstructing the rotated signal pads, but the connector route still failed. No complete USB-rotation result was saved. Stop under AGENTS.md's two-failed-fix rule; do not claim matched USB routing or signal-integrity verification. The next approach should reconsider ESD placement and route the USB pair together before surrounding power and signals.

## Resumed USB candidate — two-gate stop
After user authorization, starting routes at exact connector-pad positions resolved the USB search-grid escape failure. Two short 5V neckdowns were reduced to 0.35 mm to maintain the connector NPTH clearance, still above the 0.2 mm hard minimum. J1 ground pads use solid copper connections to avoid a starved thermal and strengthen the shell ground connection. These choices preserve the BRIEF's circuit, BOM, layer count and rule minima.
The resulting candidate has zero DRC errors and zero unconnected items but one hole-to-hole warning: the newly routed ground connection placed a via 0.2 mm from an existing same-net via, overlapping their drills. This was missed because the local search ignored same-net objects. No DRC severity was relaxed. Preserve candidate gate2.kicad_pcb and stop after the two failed gates; fabrication files remain unchanged. Next correction should reuse the existing via, not create an adjacent one.

## Review repair accepted after DRC — 2026-09-10
User authorized the remaining via correction. Removed the duplicate ground via and retained the existing overlapping copper connection; refilled copper passes DRC with zero errors, warnings and unconnected items. Main board/project now contain the repair; silk identifies REV 1.1 and manufacturing package is fab/rev2. Previous fab/rev1 is retained as history and explicitly marked superseded. ERC also remains zero. No hard constraint, BOM line, rule minimum or severity changed.
The larger power copper and shorter USB routes mitigate the review findings, but are not a controlled-impedance or thermal qualification. USB_CONN_N still changes layers while USB_CONN_P remains front-side; do not describe these as a fully matched differential pair. Physical USB and regulator load tests remain necessary. Estimated copper area is not a measured junction-temperature result.

## Supplier LED restriction — 2026-09-10 20:02–20:09 KST
After explicit user approval, accepted the assembly-service terms and uploaded BOM/CPL. All 16 BOM lines matched, but C2874885 LEDs are unchecked and marked Standard Only. Fifteen lines remain selected; do not treat this as a complete 50-part assembly order.
Searched Economic/in-stock alternatives. C55109525 WS2812B-V7 and C52941391 WS2812B-B-V6 both appear under Economic filtering and their JLCPCB part-detail pages say Economic and Standard. Attempting to select either nevertheless produces the Standard PCBA Parts rejection dialog. This inconsistency is unresolved; neither replacement persisted. No sourcing or schematic change was made.
Reviewed the manufacturer WS2812B-B-V6 PDF hosted by LCSC: https://atta.szlcsc.com/upload/public/pdf/source/20251224/2F6ED8FFFF9D3044AED3CCAA3E4BF0D9.pdf . Page 2 preserves 1=VDD,2=DOUT,3=VSS,4=DIN. Its 5050 contact geometry aligns with the existing pad centers; recommended pad height is 1.0 mm versus the existing 0.9 mm. This is preliminary replacement review, not a released footprint change. V7 geometry was not verified. Source pages: https://jlcpcb.com/partdetail/Worldsemi-WS2812B_BV6/C52941391 and https://jlcpcb.com/partdetail/Worldsemi-WS2812BV7/C55109525 .
Preserve Economic as the BRIEF hard constraint; do not silently switch to Standard or omit the LEDs. Two supplier-selection attempts failed, so stop per AGENTS.md and request permission to send the drafted support inquiry in parts/jlcpcb-economic-led-inquiry.md. No inquiry was sent yet. No order or payment occurred.

## Owner-directed procurement pause — 2026-09-10
The owner reported approximately US$123 for Standard PCBA and US$85 even with Economic PCBA, then explicitly requested a repository update and a stop because of cost. Both figures belong to the 10-board discussion; they were not independently inspected as final checkout totals. Shipping, tax and full LED population are not confirmed. Earlier estimates remain historical estimates, not reconciled invoice amounts.
Pause the Order phase and subsequent Firmware phase instead of continuing the BRIEF's back-to-back sequence. This process deviation follows the owner's explicit budget decision. Preserve all hardware features, BOM entries and the Economic hard constraint; no Standard approval, LED omission, substitution or cost-driven redesign is implied. No support inquiry, order or payment has been sent.
A later read-only browser inspection showed Standard selected, superseding the earlier Economic screen observation. The cause of that UI state change was not established and it does not relax the BRIEF constraint. That brief inspection was not recorded, contrary to the recording rule; no recording is claimed for it.
Resume only on the owner's request. Resolve Economic LED eligibility, recheck current pricing/stock and verify every assembly placement and polarity before proceeding to the payment hard stop. Existing fab/rev2 artifacts retain passed ERC/DRC results but are not a supplier-approved fabrication release.

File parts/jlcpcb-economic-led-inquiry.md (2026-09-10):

# Draft — not sent

Destination: JLCPCB support via the assembly quote page's online chat.

Hello, I am preparing a new Economic PCBA quote for 10 two-layer 60 x 40 mm boards, assembled on the top side. The current LED, WS2812B-V5/W (C2874885), is marked Standard Only.

I checked WS2812B-B-V6 (C52941391) and WS2812B-V7 (C55109525). Both appear with the Economic filter, and their part-detail pages state Economic and Standard. However, selecting either in this quote opens a Standard PCBA Parts dialog and refuses Economic assembly. Is this an actual assembly restriction or a quote/UI issue? Can either part be assembled using Economic PCBA, or is there an Economic-compatible 5050 four-pin WS2812B replacement? We need eight LEDs per board. Please do not switch the quote to Standard or place an order.

Only these board specifications and public part numbers would be sent; no account credentials or payment information.

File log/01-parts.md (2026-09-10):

# 01 — Parts preflight — 2026-09-10

## Phase
Parts preparation only. Stopped before selecting or editing design parts.

## What happened
Read the root and project AGENTS.md and BRIEF.md. No existing board or schematic was present. The KiCad MCP responded; its JLCPCB database contains 0 parts. Its UI check matched Node MCP server processes, so it does not establish that a KiCad editor is open.

Required recording was started twice, first in the sandbox and then with approved execution outside it. Both returned a PID but produced no movie. The first PID was confirmed absent. FFmpeg device enumeration showed camera and Desk View camera, but no screen capture device. The script defaults to index 1, which is Desk View on this machine, not a display. Screen Recording permission and subsequent display-device selection need resolution before continuing. No permission-denied text was returned, so the precise cause remains unverified; no workaround was attempted.

Usage tracking was attempted at session start and end. Both failed with DNS resolution errors. Per project instructions, no alternative quota source was used.

## Human interventions
Approved process inspection, recording restart, and capture-device enumeration. Asked to enable/check macOS Screen Recording permission for the application running the shell.

## Verification
- Root-cause follow-up: power logs show the display turned off again at 15:13:46, before the 15:13:53 recording attempt. Keeping user activity and display wake asserted together with `caffeinate -u -d -t 45` restored screen indices 2 and 3. A foreground FFmpeg capture from index 2 exited 0; ffprobe validated `media/raw/recording-diagnostic.mov` as 2.933334 seconds, 1,093,232 bytes. Screen capture permission works in this execution context. The failures involved display sleep and the script's incorrect default index 1, not demonstrated permission denial. The earlier 5-second user-active assertion expired too soon; the later display-only assertion did not keep this setup awake. Long-session recording is still unverified.
- Follow-up correction: the user suggested display sleep. At 15:13:31, `caffeinate -u -t 5` produced a `Display is turned on` power-log event; FFmpeg then enumerated `Capture screen 0` and `Capture screen 1` at indices 2 and 3. Display sleep was confirmed as a factor; the earlier permission diagnosis was premature. A subsequent recording attempt at index 2 still failed with `Invalid device index`, indicating that the transient device list was not stable. Recording remains unverified; no movie was generated.
- ERC errors: not run; no schematic exists.
- DRC errors: not run; no PCB exists.
- Confirmed: project instructions read; MCP responds; parts database empty; no recording movie generated; capture device list lacks a display.
- Commands run: scripts/rec-start.sh run01 (twice), scripts/rec-stop.sh, scripts/usage.sh session-start and session-end, FFmpeg AVFoundation device enumeration.
- Unverified: recording permissions, all parts, all phase gates, hardware operation.

## Scoreboard
DRC N/A / ERC N/A / Astra usage unavailable (DNS failure) / human time not measured.

## Media candidates
No valid recording or markers. Neither attempted recording generated a movie, so there are no clips to recommend.

## Resumed parts phase — 15:18–15:26 KST
Parts gate passed: 19 LCSC entries present in the downloaded catalog and all 19 symbol/footprint pairs exist in KiCad 10.0.6. Evidence: parts/evidence/library-gate.json and jlcpcb-selected.json. 16 SMT BOM lines, 50 placements, seven extended SMT types; reasons and cost estimate in parts/DECISIONS.md. Live checkout stock, datasheet mechanical matching and hardware performance are not established by the existence gate.

MCP downloader timed out at 30 seconds but continued and populated 632,871 records. A CLI fallback failed because system Python lacked pcbnew; no server code was changed. Database success was verified with MCP stats/search. GUI process inspection found no KiCad editor. No design files existed before this phase.

Weekly usage 65% at resumed start and parts gate. Five-hour window absent, confirmed by user. Human input requested: public repo URL for QR; not yet supplied. Recording now grows normally using device 2 with a persistent awake assertion.

Media candidates: media/raw/run01-20260910-151816.mov; 00:01:16 recording and library verification; 00:05:20 parts gate passed. ERC/DRC not run yet.

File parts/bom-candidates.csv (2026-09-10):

role | qty | mpn | manufacturer | lcsc | basic_or_extended | unit_price_usd_at_10 | stock | kicad_symbol | kicad_footprint | datasheet_url | note
mcu | 1 | ESP32-C3-WROOM-02-N4 | Espressif Systems | C2934560 | extended | 2.8942 | 3702 | RF_Module:ESP32-C3-WROOM-02 | Astra:ESP32-C3-WROOM-02 | https://jlcpcb.com/api/file/downloadByFileSystemAccessId/8588954590158983169 | 4 MB; onboard antenna; SMT; standard footprint derivative: thermal drills 0.3 mm
ldo | 1 | AMS1117-3.3 | Advanced Monolithic Systems | C6186 | basic | 0.2003 | 2007447 | Regulator_Linear:AMS1117-3.3 | Package_TO_SOT_SMD:SOT-223-3_TabPin2 | https://jlcpcb.com/api/file/downloadByFileSystemAccessId/8550724073479806976 | 1 A rated; SMT
rgb_led | 8 | WS2812B-V5/W | Worldsemi | C2874885 | extended | 0.1099 | 332068 | LED:WS2812B | Astra:LED_WS2812B_PLCC4_5.0x5.0mm_P3.2mm | https://jlcpcb.com/api/file/downloadByFileSystemAccessId/8588918861252583424 | 5 V; SMT
usb_c | 1 | TYPE-C-31-M-12 | Korean Hroparts Elec | C165948 | extended | 0.1858 | 89797 | Connector:USB_C_Receptacle_USB2.0_16P | Astra:USB_C_Receptacle_HRO_TYPE-C-31-M-12 | https://jlcpcb.com/api/file/downloadByFileSystemAccessId/8550723676069908480 | 16 contacts; SMT contacts with shell anchors
qwiic | 1 | SM04B-SRSS-TB(LF)(SN) | JST | C160404 | extended | 0.2262 | 7284 | Connector_Generic:Conn_01x04 | Connector_JST:JST_SH_SM04B-SRSS-TB_1x04-1MP_P1.00mm_Horizontal | https://jlcpcb.com/api/file/downloadByFileSystemAccessId/8588893837427150848 | 1 GND 2 3V3 3 SDA 4 SCL; SMT
buttons | 4 | TS-1088R-02026 | XUNPU | C455280 | extended | 0.0632 | 157033 | Switch:SW_Push | Astra:SW_SPST_TS-1088-xR020 | https://jlcpcb.com/api/file/downloadByFileSystemAccessId/8756508134237966336 | BOOT RESET USER1 USER2; SMT
led_level_shift | 1 | SN74AHCT1G125DBVR | Texas Instruments | C7484 | extended | 0.1037 | 22987 | 74xGxx:74AHCT1G125 | Package_TO_SOT_SMD:SOT-23-5 | https://www.ti.com/cn/lit/gpn/sn74ahct1g125 | TI 5 V TTL threshold buffer; SMT
usb_esd | 1 | USBLC6-2SC6 | STMicroelectronics | C7519 | extended | 0.1639 | 36380 | Power_Protection:USBLC6-2SC6 | Package_TO_SOT_SMD:SOT-23-6 | https://jlcpcb.com/api/file/downloadByFileSystemAccessId/8579714554416455680 | ST ESD protection; SMT
buzzer_driver | 1 | S8050 J3Y(RANGE:200-350) | Jiangsu Changjing Electronics Technology Co Ltd | C2146 | basic | 0.0146 | 1243675 | Transistor_BJT:SS8050 | Package_TO_SOT_SMD:SOT-23 | https://jlcpcb.com/api/file/downloadByFileSystemAccessId/8579710511040020480 | pin 1 B 2 E 3 C; SMT
cc_and_pull_resistors | 10 | 0603WAF5101T5E | UNI ROYAL Uniroyal Elec | C23186 | basic | 0.0019 | 3775920 | Device:R | Resistor_SMD:R_0603_1608Metric | https://jlcpcb.com/api/file/downloadByFileSystemAccessId/8579706277024620544 | 5.1k CC x2 EN BOOT strap2 strap8 I2C x2 LED pulldown base pulldown; SMT
buzzer_resistors | 2 | 0603WAF1001T5E | UNI ROYAL Uniroyal Elec | C21190 | basic | 0.0039 | 8013731 | Device:R | Resistor_SMD:R_0603_1608Metric | https://jlcpcb.com/api/file/downloadByFileSystemAccessId/8579706098733010944 | 1k base series and piezo discharge; SMT
led_series | 1 | 0603WAF3300T5E | UNI ROYAL Uniroyal Elec | C23138 | basic | 0.0016 | 1090237 | Device:R | Resistor_SMD:R_0603_1608Metric | https://jlcpcb.com/api/file/downloadByFileSystemAccessId/8579706223213461504 | 330 ohm; SMT
usb_series | 2 | 0603WAF220JT5E | UNI ROYAL Uniroyal Elec | C23345 | basic | 0.0017 | 2657294 | Device:R | Resistor_SMD:R_0603_1608Metric | https://jlcpcb.com/api/file/downloadByFileSystemAccessId/8579706330933874688 | 22 ohm; SMT
decoupling | 11 | CC0603KRX7R9BB104 | YAGEO | C14663 | basic | 0.0106 | 12618106 | Device:C | Capacitor_SMD:C_0603_1608Metric | https://jlcpcb.com/api/file/downloadByFileSystemAccessId/8667086713681608704 | 100 nF; MCU buffer ESD and 8 LEDs; SMT
input_and_reset_cap | 2 | CL10A105KB8NNNC | Samsung Electro Mechanics | C15849 | basic | 0.0297 | 5979916 | Device:C | Capacitor_SMD:C_0603_1608Metric | https://jlcpcb.com/api/file/downloadByFileSystemAccessId/8556213788459761664 | 1 uF; VBUS input and EN; SMT
ldo_output_bulk | 3 | TAJA106K016RNJ | Kyocera AVX | C7171 | basic | 0.2081 | 1016523 | Device:C_Polarized | Capacitor_Tantalum_SMD:CP_EIA-3216-18_Kemet-A | https://jlcpcb.com/api/file/downloadByFileSystemAccessId/8579707377870036992 | 3 parallel 10 uF 16 V tantalum = 30 uF nominal; SMT
passive_buzzer | 1 | PS1240P02BT | TDK | C76871 | extended | 0.1633 | 6077 | Device:Buzzer | Buzzer_Beeper:Buzzer_TDK_PS1240P02BT_D12.2mm_H6.5mm | https://jlcpcb.com/api/file/downloadByFileSystemAccessId/8559368611904184320 | THT; owner solders; no feeder fee
oled_header | 1 | B-2100S04P-A110 | Ckmtw Shenzhen Cankemeng | C124378 | extended | 0.0554 | 66521 | Connector_Generic:Conn_01x04 | Connector_PinHeader_2.54mm:PinHeader_1x04_P2.54mm_Vertical | https://jlcpcb.com/api/file/downloadByFileSystemAccessId/8588889829354037248 | THT; owner solders OLED via header; 1 GND 2 3V3 3 SCL 4 SDA
expansion_header | 1 | B-2100S10P-A110 | Ckmtw Shenzhen Cankemeng | C124372 | extended | 0.0777 | 2146 | Connector_Generic:Conn_01x10 | Connector_PinHeader_2.54mm:PinHeader_1x10_P2.54mm_Vertical | https://jlcpcb.com/api/file/downloadByFileSystemAccessId/8588892459200098304 | THT; owner solders; six remaining GPIO plus 3V3 5V and two GND

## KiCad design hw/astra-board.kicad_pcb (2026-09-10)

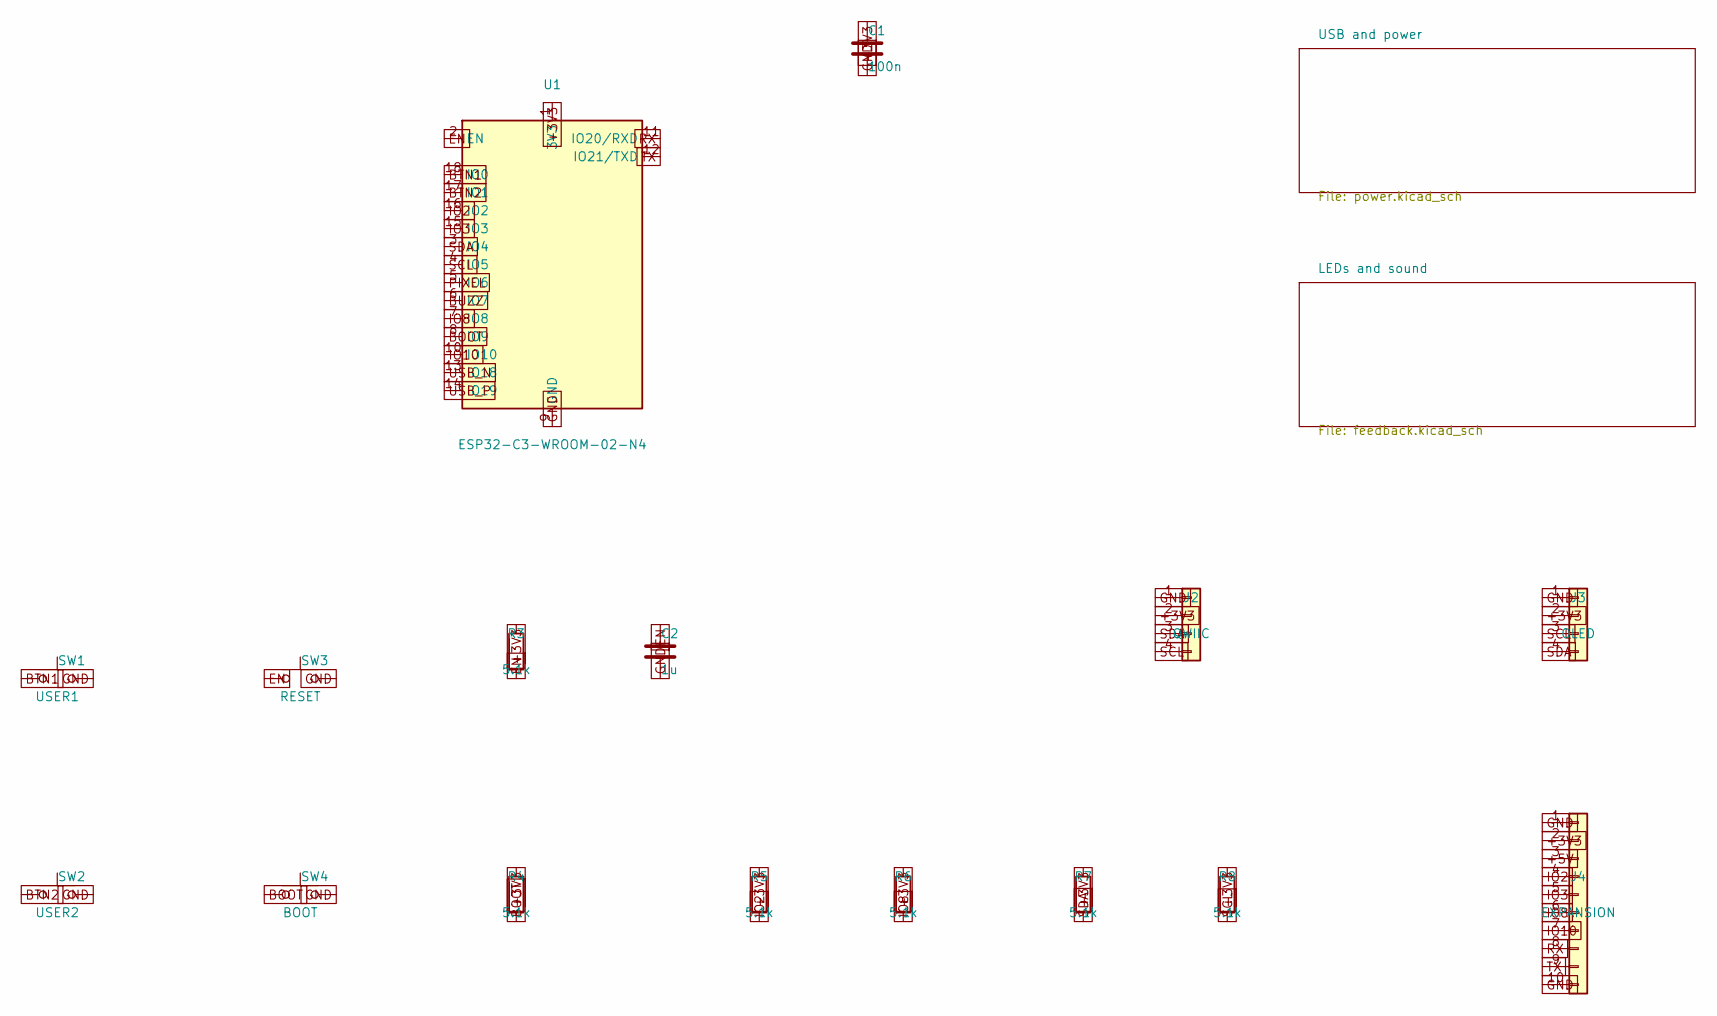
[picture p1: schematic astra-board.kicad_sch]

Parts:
C1: 100n; C_0603_1608Metric; MPN CC0603KRX7R9BB104; LCSC C14663
C2: 1u; C_0603_1608Metric; MPN CL10A105KB8NNNC; LCSC C15849
J2: QWIIC; JST_SH_SM04B-SRSS-TB_1x04-1MP_P1.00mm_Horizontal; MPN SM04B-SRSS-TB(LF)(SN); LCSC C160404
J3: OLED; PinHeader_1x04_P2.54mm_Vertical; MPN B-2100S04P-A110; LCSC C124378
J4: EXPANSION; PinHeader_1x10_P2.54mm_Vertical; MPN B-2100S10P-A110; LCSC C124372
R3, R4, R5, R6, R7, R8: 5.1k; R_0603_1608Metric; MPN 0603WAF5101T5E; LCSC C23186
SW1: USER1; SW_SPST_TS-1088-xR020; MPN TS-1088R-02026; LCSC C455280
SW2: USER2; SW_SPST_TS-1088-xR020; MPN TS-1088R-02026; LCSC C455280
SW3: RESET; SW_SPST_TS-1088-xR020; MPN TS-1088R-02026; LCSC C455280
SW4: BOOT; SW_SPST_TS-1088-xR020; MPN TS-1088R-02026; LCSC C455280
U1: ESP32-C3-WROOM-02-N4; ESP32-C3-WROOM-02; MPN ESP32-C3-WROOM-02-N4; LCSC C2934560

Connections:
+3V3: C1.1, J2.2, J3.2, J4.2, R3.1, R4.1, R5.1, R6.1, R7.1, R8.1, U1.1 (3V3); also elsewhere on the board
+5V: J4.3; also elsewhere on the board
BOOT: R4.2, SW4.1, U1.8 (IO9)
BTN1: SW1.1, U1.18 (IO0)
BTN2: SW2.1, U1.17 (IO1)
BUZZ: U1.6 (IO7); also elsewhere on the board
EN: C2.1, R3.2, SW3.1, U1.2 (EN)
GND: C1.2, C2.2, J2.1, J3.1, J4.1, J4.10, SW1.2, SW2.2, SW3.2, SW4.2, U1.9 (GND), U1.19 (GND); also elsewhere on the board
IO2: J4.4, R5.2, U1.16 (IO2)
IO3: J4.5, U1.15 (IO3)
IO8: J4.6, R6.2, U1.7 (IO8)
IO10: J4.7, U1.10 (IO10)
PIXEL: U1.5 (IO6); also elsewhere on the board
RX: J4.8, U1.11 (IO20/RXD)
SCL: J2.4, J3.3, R8.2, U1.4 (IO5)
SDA: J2.3, J3.4, R7.2, U1.3 (IO4)
TX: J4.9, U1.12 (IO21/TXD)
USB_N: U1.13 (IO18); also elsewhere on the board
USB_P: U1.14 (IO19); also elsewhere on the board

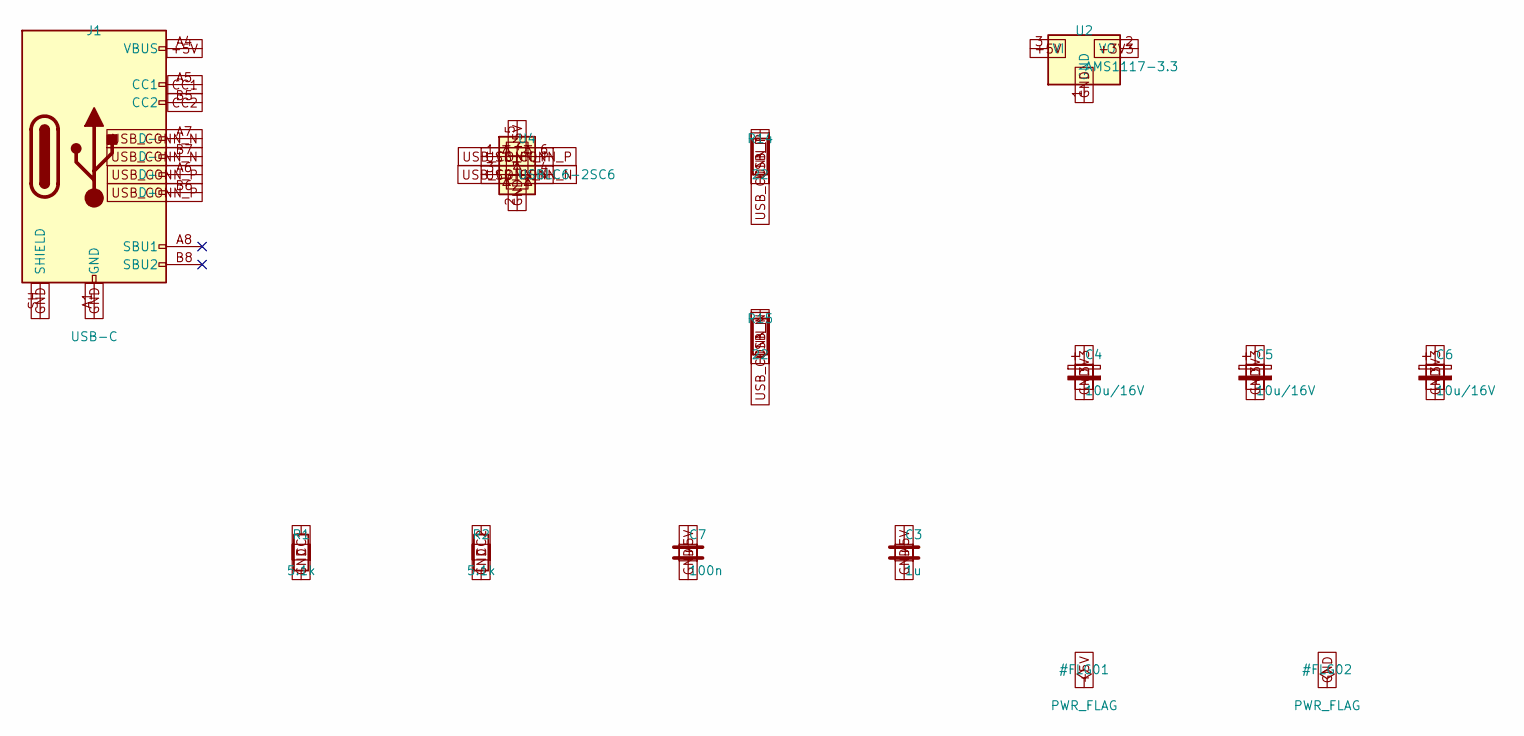
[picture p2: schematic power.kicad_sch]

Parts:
C3: 1u; C_0603_1608Metric; MPN CL10A105KB8NNNC; LCSC C15849
C4, C5, C6: 10u/16V; CP_EIA-3216-18_Kemet-A; MPN TAJA106K016RNJ; LCSC C7171
C7: 100n; C_0603_1608Metric; MPN CC0603KRX7R9BB104; LCSC C14663
J1: USB-C; USB_C_Receptacle_HRO_TYPE-C-31-M-12; MPN TYPE-C-31-M-12; LCSC C165948
R1, R2: 5.1k; R_0603_1608Metric; MPN 0603WAF5101T5E; LCSC C23186
R14, R15: 22; R_0603_1608Metric; MPN 0603WAF220JT5E; LCSC C23345
U2: AMS1117-3.3; SOT-223-3_TabPin2; MPN AMS1117-3.3; LCSC C6186
U4: USBLC6-2SC6; SOT-23-6; MPN USBLC6-2SC6; LCSC C7519

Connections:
+3V3: C4.1, C5.1, C6.1, U2.2 (VO); also elsewhere on the board
+5V: C3.1, C7.1, J1.A4 (VBUS), J1.A9 (VBUS), J1.B4 (VBUS), J1.B9 (VBUS), U2.3 (VI), U4.5 (VBUS); also elsewhere on the board
CC1: J1.A5 (CC1), R1.1
CC2: J1.B5 (CC2), R2.1
GND: C3.2, C4.2, C5.2, C6.2, C7.2, J1.A1 (GND), J1.A12 (GND), J1.B1 (GND), J1.B12 (GND), J1.SH (SHIELD), R1.2, R2.2, U2.1 (GND), U4.2 (GND); also elsewhere on the board
USB_CONN_N: J1.A7 (D-), J1.B7 (D-), R15.1, U4.3 (I/O2), U4.4 (I/O2)
USB_CONN_P: J1.A6 (D+), J1.B6 (D+), R14.1, U4.1 (I/O1), U4.6 (I/O1)
USB_N: R15.2; also elsewhere on the board
USB_P: R14.2; also elsewhere on the board

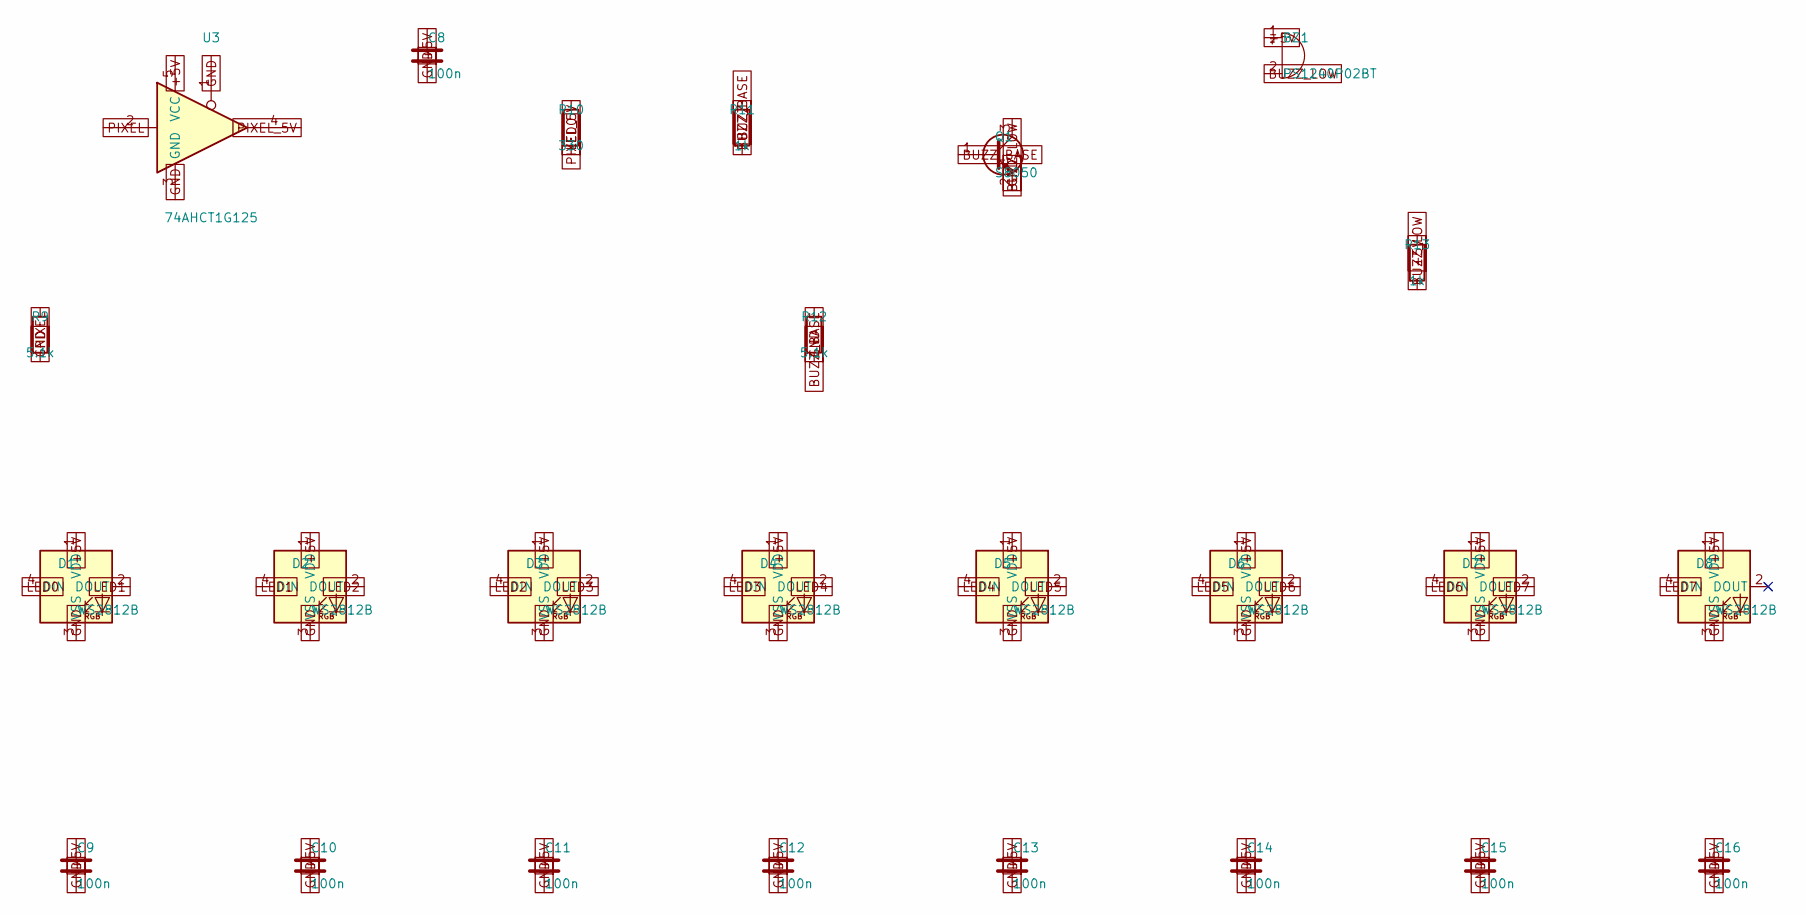
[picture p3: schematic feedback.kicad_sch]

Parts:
BZ1: PS1240P02BT; Buzzer_TDK_PS1240P02BT_D12.2mm_H6.5mm; MPN PS1240P02BT; LCSC C76871
C8, C9, C10, C11, C12, C13, C14, C15, C16: 100n; C_0603_1608Metric; MPN CC0603KRX7R9BB104; LCSC C14663
D1, D2, D3, D4, D5, D6, D7, D8: WS2812B; LED_WS2812B_PLCC4_5.0x5.0mm_P3.2mm; MPN WS2812B-V5/W; LCSC C2874885
Q1: S8050; SOT-23; MPN S8050 J3Y(RANGE:200-350); LCSC C2146
R9, R12: 5.1k; R_0603_1608Metric; MPN 0603WAF5101T5E; LCSC C23186
R10: 330; R_0603_1608Metric; MPN 0603WAF3300T5E; LCSC C23138
R11, R13: 1k; R_0603_1608Metric; MPN 0603WAF1001T5E; LCSC C21190
U3: 74AHCT1G125; SOT-23-5; MPN SN74AHCT1G125DBVR; LCSC C7484

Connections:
+5V: BZ1.1 (+), C8.1, C9.1, C10.1, C11.1, C12.1, C13.1, C14.1, C15.1, C16.1, D1.1 (VDD), D2.1 (VDD), D3.1 (VDD), D4.1 (VDD), D5.1 (VDD), D6.1 (VDD), D7.1 (VDD), D8.1 (VDD), R13.1, U3.5 (VCC); also elsewhere on the board
BUZZ: R11.1; also elsewhere on the board
BUZZ_BASE: Q1.1 (B), R11.2, R12.1
BUZZ_LOW: BZ1.2 (-), Q1.3 (C), R13.2
GND: C8.2, C9.2, C10.2, C11.2, C12.2, C13.2, C14.2, C15.2, C16.2, D1.3 (VSS), D2.3 (VSS), D3.3 (VSS), D4.3 (VSS), D5.3 (VSS), D6.3 (VSS), D7.3 (VSS), D8.3 (VSS), Q1.2 (E), R9.2, R12.2, U3.1, U3.3 (GND); also elsewhere on the board
LED0: D1.4 (DIN), R10.2
LED1: D1.2 (DOUT), D2.4 (DIN)
LED2: D2.2 (DOUT), D3.4 (DIN)
LED3: D3.2 (DOUT), D4.4 (DIN)
LED4: D4.2 (DOUT), D5.4 (DIN)
LED5: D5.2 (DOUT), D6.4 (DIN)
LED6: D6.2 (DOUT), D7.4 (DIN)
LED7: D7.2 (DOUT), D8.4 (DIN)
PIXEL: R9.1, U3.2; also elsewhere on the board
PIXEL_5V: R10.1, U3.4

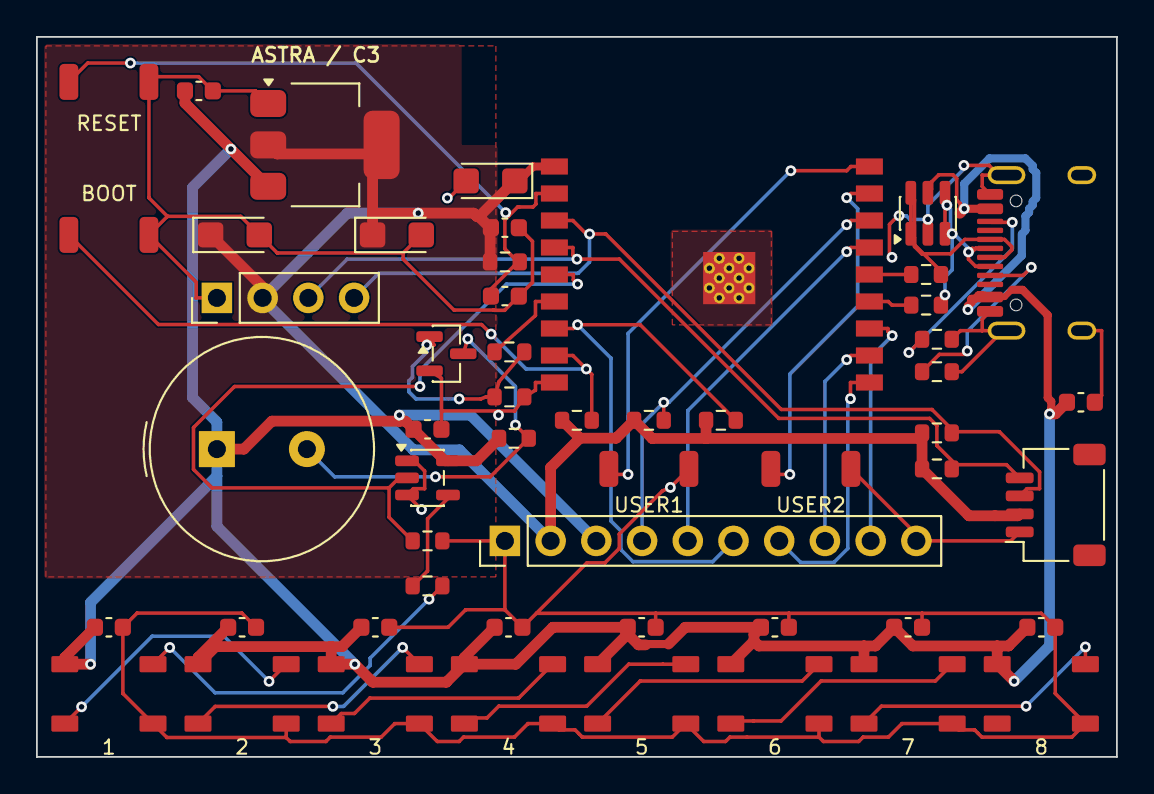
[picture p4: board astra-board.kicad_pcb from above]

Board: 2 copper layers, 60.0 x 40.0 mm, 53 parts (0 on the bottom side), 34 nets.

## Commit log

2026-09-10 Add initial Astra board design and experiment record
    [astra-board.kicad_pcb, astra-board.kicad_sch, bom-candidates.csv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]
2026-09-10 Add verified repository QR and manufacturing review package
    [BOM.csv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]
2026-09-10 Revise USB placement and power copper; regenerate verified fabrication package
    [BOM.csv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]
2026-09-10 Document supplier Economic LED restriction and draft clarification inquiry
